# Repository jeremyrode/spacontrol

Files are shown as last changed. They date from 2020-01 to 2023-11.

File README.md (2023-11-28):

# spacontrol
IoT Work for my Caldera Vacanza Hot Tub

## General Info
I have a Caldera Vacanza Hot Tub in my house and I love it, with one exception: it heats on demand.  With electric time of use (TOU) rates, I can save money if the hot tub would heat during off-peak rates.  Goal is to reverse engineer the protocol used to signal button presses.  Phase 1 is to have a cron script adjust the setpoints so that the heating occurs during off-peak hours.  Phase 2 (current) is to use Google Calendar to schedule the virtual button presses to follow the complex TOU schedule.  Phase 3 (In progress) is to reverse engineer the status screen protocol, and forward the status to a website.  This has been stymied by the complex bit banging that is going on between these systems.  The patterns seem to change, see Keypad Commands section.

## Status

Phase 2 is working well for a year now, it pulls the desired temprature from a [Google Calendar via the API](/googlecalendardaemon), then schedules them.  I thought this was clever, so [I broke out this code as an example](https://github.com/jeremyrode/CalendarScraper) and it made [HACAKADAY!](https://hackaday.com/2022/10/25/using-google-calendar-for-machines-to-keep-track-of-human-days/)

## Quickstart

Easiest way is to have a cron job running tools/temp_up.js and tools/temp_down.js at the appropriate times for cheap TOU power.

Add the following to the crontab:
```
08 0 * * * /home/pi/spacontrol/tools/temp_down.js
10 0 * * * /home/pi/spacontrol/tools/temp_up.js
50 5 * * * /home/pi/spacontrol/tools/temp_down.js
```
Here at 12:08 AM the temp is turned down to ensure a start from 80 deg, as this code is "open-loop".  At 12:10 AM the temp is turned up to 103, then at 5:50AM the temp is turned back down to 80 deg.  Ideally the spa will be at ~100 deg in the evening when I'm ready to go in.

## Detailed Status
I have successfully reverse engineered the button press protocol.  Playing the protocol back proved to be tricky, as the keypad seems to be polled, so even when no buttons are pressed, the keypad reports status every ~40ms.  Injecting commands on top of the polled screen traffic does not result in the controller registering a button press. I suspect there is a switch "debouncing" algorithm that only registers a press if button polls several times in a row.  This necessitated a more complicated hardware design, where a GPIO on the raspberry pi is used to switch a mux, muting the traffic from the screen while virtual button presses are generated.

## Screen status 
77 degrees
Mostly
4a962bf252fefefa6600
I saw one:
4a962be452fefefa6600
80 degrees
4a962bf252fefefa6600

## Keypad Commands

The keypad seems to report status every ~40ms back to the controller.  I believe it is polled based off of commands sent to the pad, as the traffic seems to halt if the controller->keypad serial line is disconnected.  Baud rate is 115200, with 2-stop bits, but this doesn't seem to matter.

| Button  | Code (Hex) |
| :---: |:----:|
| Idle | 584D5300036b00000166 |
| Unknown / Idle  | 584D5300014b0144 |
| Jets | 584D5300036b00100176 |
| Temp Down | 584D5300036b0008016e |
| Temp Up | 584D5300036b00020168 |
| Lights | 584D5300036b00200186 |

Some how this has changed???

Now I'm seeing at idle (captured with serial_test.py):

58534d00010000f958534d00031a00830198

58534d00031a00830198

58534d00031a00830198

58534d00031a00830198

58534d00010000f958534d00031a00830198

58534d00031a00830198

No idea!, but the old commands seem to work on the sending side!

Seems to persist.  Is the the raspberryPi or the mainboard?

Putting this on hold, quite frankly it doesn't matter, the old commands above still work.

## Hardware details

This is the connector we would like to inject commands into:

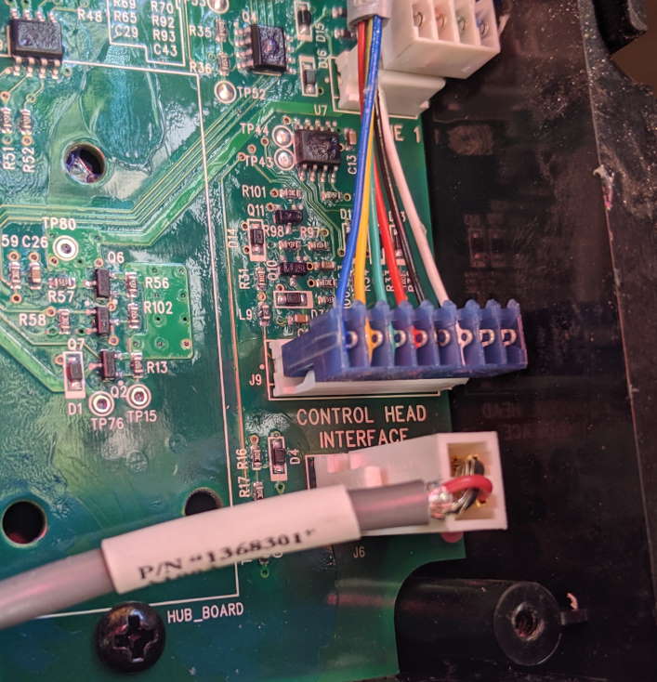
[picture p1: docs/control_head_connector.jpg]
Control Head Connector


Probing with an oscilloscope revealed the following pinout:

| Pin #  | Function |
| :---:|:----:|
| 1 | Screen->Controller (RS-422) |
| 2 | +12V |
| 3 | Controller->Screen (RS-422) |
| 4 | GND |
| 5 | Controller->Screen (RS-422) |
| 6 | Screen->Controller (RS-422) |

I have purposely not marked the RS-422 polarity, as I want to double check.  The PCB has jumpers that toggle the MAX3089's polarity inputs, so the PCB as designed will work with either polarity.

My first hand-built prototype.  

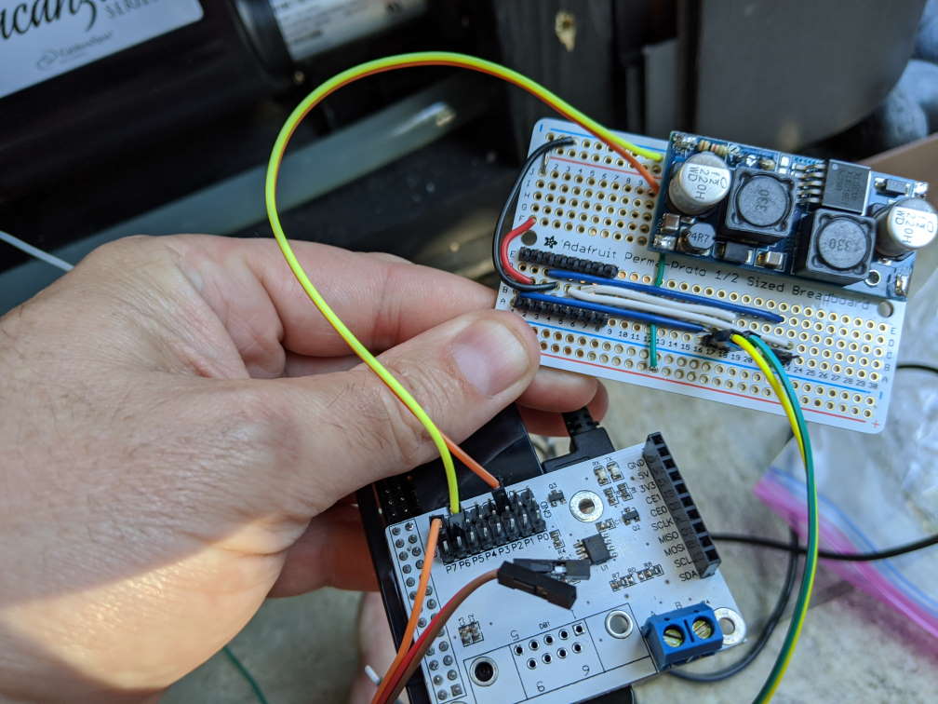
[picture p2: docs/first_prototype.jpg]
First Prototype


This is basically a break-out board, with a 12V to 5V converter for convenience so that I don't have to use an extension cord with a USB power supply to power the Pi Zero.  I used the [sparkfun RS485 shield](https://www.sparkfun.com/products/retired/13706) I had laying around from my [last reverse engineering project](https://github.com/jeremyrode/elancontrol).

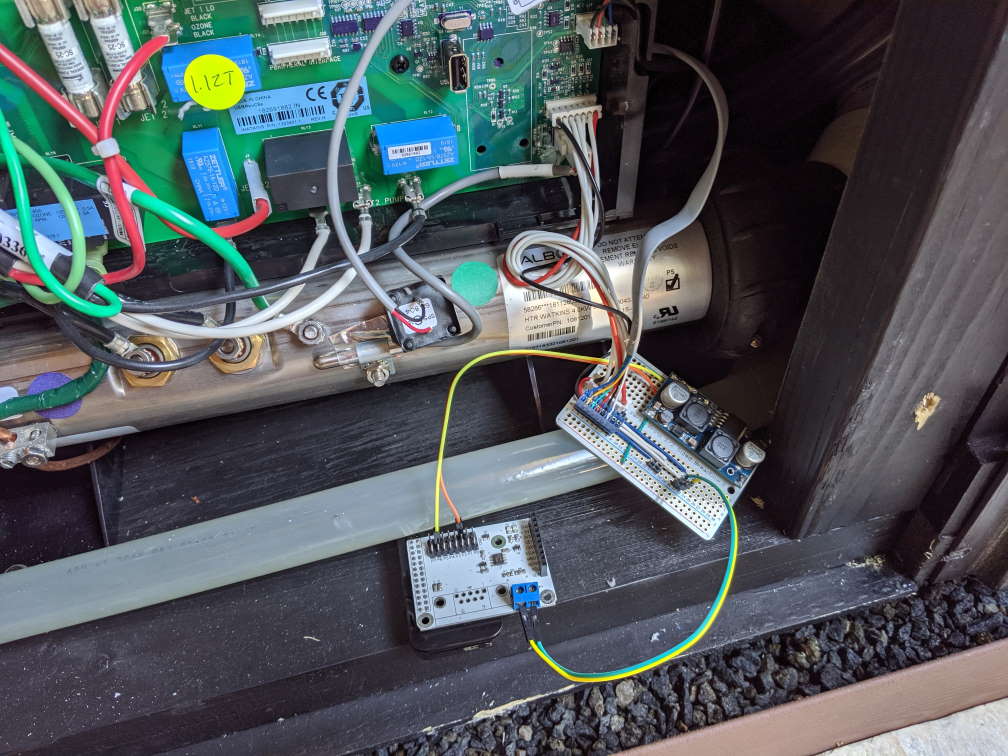
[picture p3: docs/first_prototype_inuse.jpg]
First Prototype In Use


This prototype successfully captured screen codes, and could play the codes back, but as its RS-422 transmitter is in parallel with the screens transmitter code playback never worked.  I suspect that because of the polled nature of the system transmitting status every 40ms, that when a button press code is injected some sort of button debouncing algorithm rejects the single button press code.  At this point I bit the bullet and I designed a raspberry Pi Zero "hat" PCB (see the PCB directory) that uses a MAX14778 MUX to inject commands (using a MAX3089 to translate the Pi's serial port to the spa's RS-422), defaulting to a passthrough mode where the normal screen traffic is unaffected, selected via GPIO5.  I also threw in a 12V to 5V regulator to power the raspberry Pi from the 12V screen supply.  Watch out the Vacanza controller will power cycle this 12V if valid commands are not returned for a couple of seconds or so!  That threw my debugging through a loop!

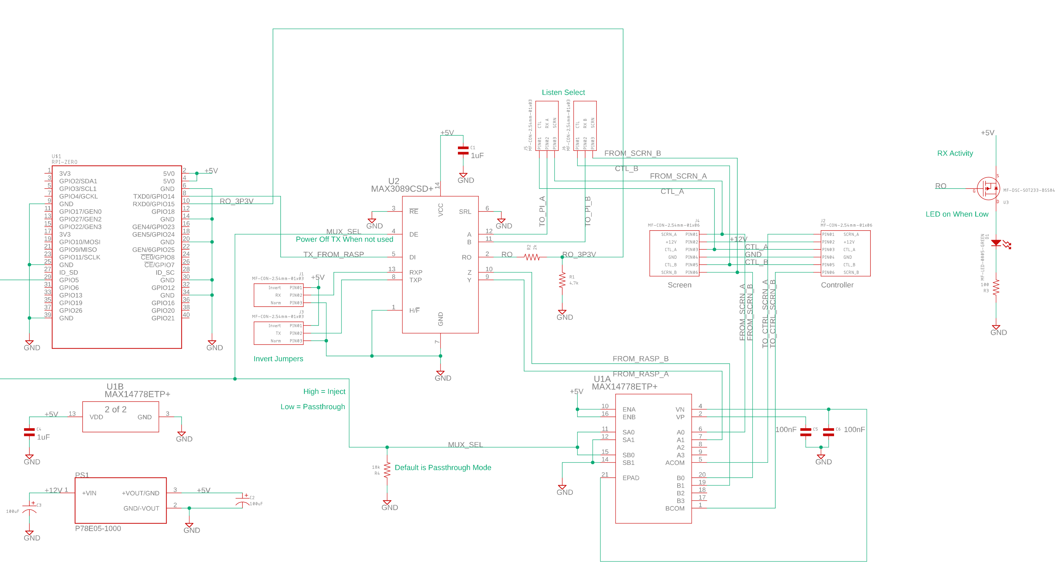
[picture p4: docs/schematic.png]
Interface PCB Schematic


Trusty Macrofab (I highly recommend!) fabricated it no problem:

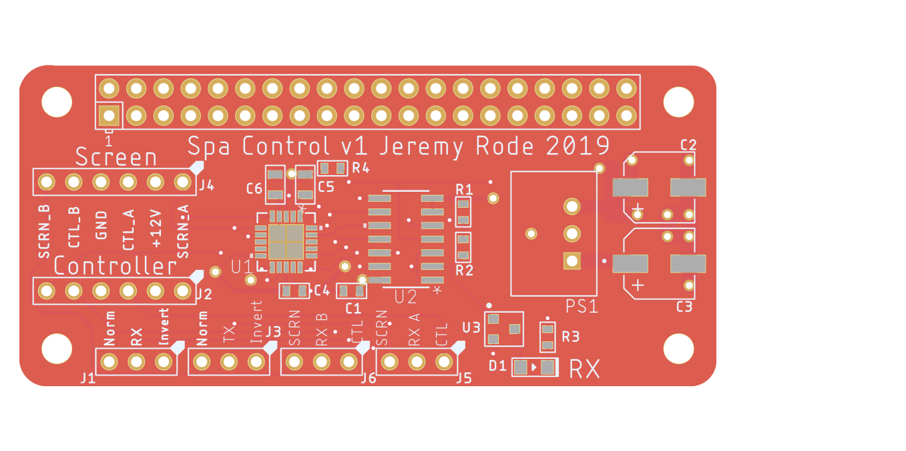
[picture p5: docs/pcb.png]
PCB


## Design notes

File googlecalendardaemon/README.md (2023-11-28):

# Spacontrol via Google calendar
## Status
Working for a year now!

## Details
Code polls a specified Google calendar, looks for events with 'Temp:'.  If these events are found, create the correct sequence of injected virtual button presses to achieve the desired temperature, no matter what the current setting is.

I plan to eventually incorporate circulation into the code, but first I need to get the current state from the screen.  Unlike the temperature where a known state can be achieved by hitting the limit, the jets button cycles through the states.  Without a method of determining the current state, there is no way to get the system reliably into a given state.

Default is 80 deg for all time except if there is no event.

## OAuth Drama

Google made getting a refresh token much harder (needing a publically avalible domain), so I switched this to a API key access method.  This is much easier, but has the side effect of only being able to access publically avalible calendars.  I see no need to keep my electric schedule private, so I make my spa control calendar public.

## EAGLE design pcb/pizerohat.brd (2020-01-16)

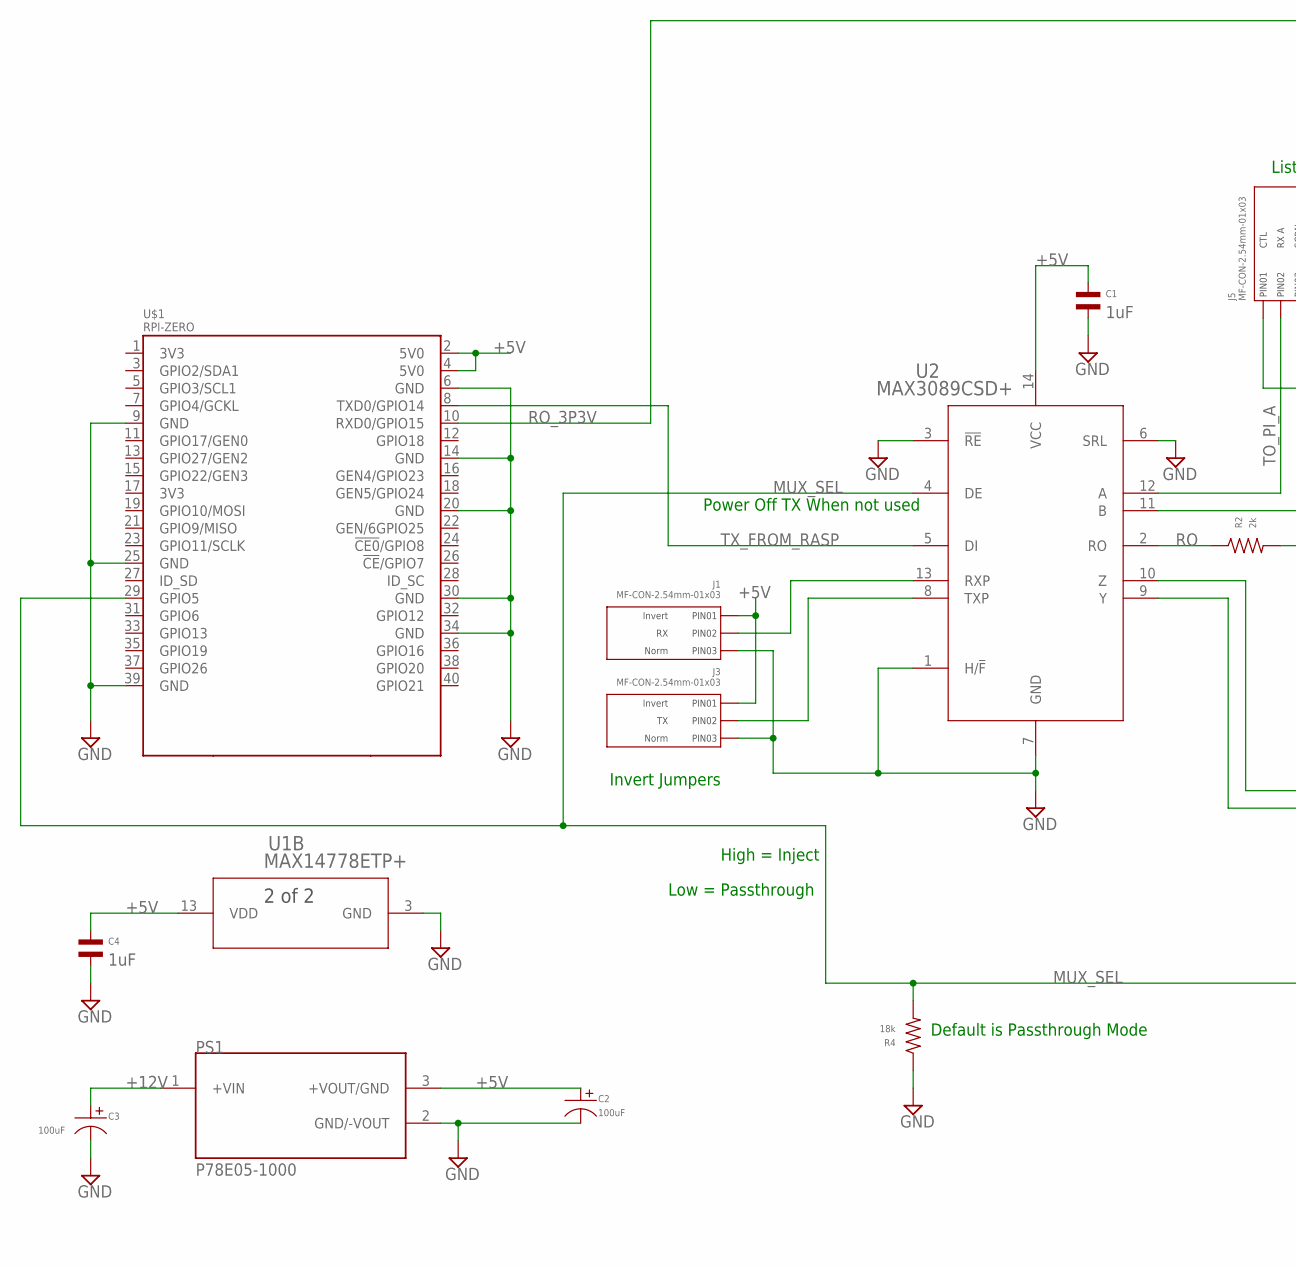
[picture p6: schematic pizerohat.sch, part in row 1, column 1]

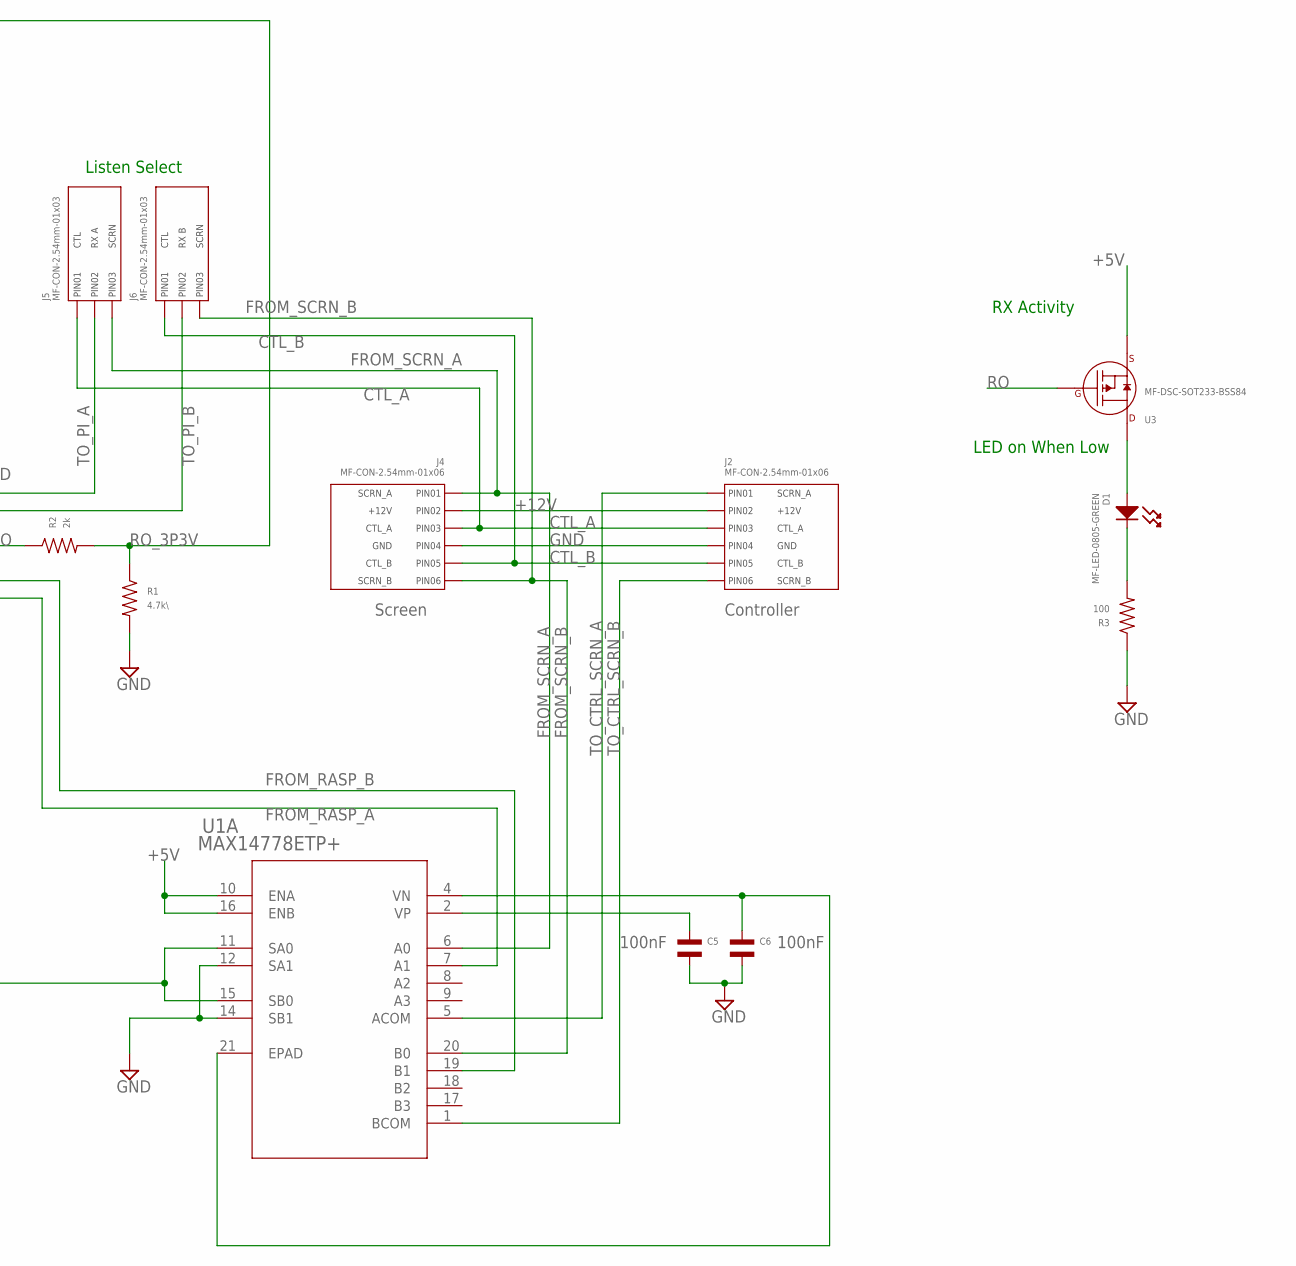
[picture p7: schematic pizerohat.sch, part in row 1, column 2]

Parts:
C1, C4: CAPACITOR_NP_0603; C0603; MPN MF-CAP-0603-1uF
C2, C3: 100uF; CP6.3MM; MPN MF-CAP-6.3MM-100uF
C5, C6: CAPACITOR_NP_0805; C0805; MPN MF-CAP-0805-0.1uF
D1: MF-LED-0805-GREEN; LED0805
J1, J3, J5, J6: MF-CON-2.54mm-01x03; PTH_2.54MM_01X03
J2, J4: MF-CON-2.54mm-01x06; PTH_2.54MM_01X06
PS1: P78E05-1000; CONV_P78E05-1000; MPN P78E05-1000
R1: 4.7k\; R0603; MPN MF-RES-0603-4.7K
R2: 2k; R0603; MPN MF-RES-0603-2K
R3: 100; R0603; MPN MF-RES-0603-100
R4: 18k; R0603; MPN MF-RES-0603-18K
U1: MAX14778ETP+; 21-0140L_T2055-4; MPN MAX14778ETP+
U2: MAX3089CSD+; 21-0041B_14; MPN MAX3089CSD+
U3: MF-DSC-SOT233-BSS84; SOT-23-3
U$1: RPI-ZERO; RASPBERRYPI_BASTELSTUBE_V13_RASPI_BOARD_B+_FULL

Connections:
+5V: C1.P$1, C2.P$1, C4.P$1, J1.P$1 (PIN1), J3.P$1 (PIN1), PS1.3 (+VOUT/GND), U1.10 (ENA), U1.13 (VDD), U1.16 (ENB), U2.14 (VCC), U3.P$2 (SOURCE), U$1.2 (5V0), U$1.4 (5V0)
+12V: C3.P$1, J2.P$2 (PIN2), J4.P$2 (PIN2), PS1.1 (+VIN)
CTL_A: J2.P$3 (PIN3), J4.P$3 (PIN3), J5.P$1 (PIN1)
CTL_B: J2.P$5 (PIN5), J4.P$5 (PIN5), J6.P$1 (PIN1)
FROM_RASP_A: U1.7 (A1), U2.9 (Y)
FROM_RASP_B: U1.19 (B1), U2.10 (Z)
FROM_SCRN_A: J4.P$1 (PIN1), J5.P$3 (PIN3), U1.6 (A0)
FROM_SCRN_B: J4.P$6 (PIN6), J6.P$3 (PIN3), U1.20 (B0)
GND: C1.P$2, C2.P$2, C3.P$2, C4.P$2, C5.P$2, C6.P$2, J1.P$3 (PIN3), J2.P$4 (PIN4), J3.P$3 (PIN3), J4.P$4 (PIN4), PS1.2 (GND/-VOUT), R1.P$2, R3.P$1, R4.P$1, U1.3 (GND), U1.12 (SA1), U1.14 (SB1), U2.1 (H/!F), U2.3 (!RE), U2.6 (SRL), U2.7 (GND), U$1.6 (GND), U$1.9 (GND), U$1.14 (GND), U$1.20 (GND), U$1.25 (GND), U$1.30 (GND), U$1.34 (GND), U$1.39 (GND)
MUX_SEL: R4.P$2, U1.11 (SA0), U1.15 (SB0), U2.4 (DE), U$1.29 (GPIO5)
unnamed: J1.P$2 (PIN2), U2.13 (RXP)
unnamed: J3.P$2 (PIN2), U2.8 (TXP)
unnamed: C6.P$1, U1.4 (VN), U1.21 (EPAD)
unnamed: D1.CATHODE, R3.P$2
unnamed: C5.P$1, U1.2 (VP)
unnamed: D1.ANODE, U3.P$3 (DRAIN)
RO: R2.P$1, U2.2 (RO), U3.P$1 (GATE)
RO_3P3V: R1.P$1, R2.P$2, U$1.10 (RXD0/GPIO15)
TO_CTRL_SCRN_A: J2.P$1 (PIN1), U1.5 (ACOM)
TO_CTRL_SCRN_B: J2.P$6 (PIN6), U1.1 (BCOM)
TO_PI_A: J5.P$2 (PIN2), U2.12 (A)
TO_PI_B: J6.P$2 (PIN2), U2.11 (B)
TX_FROM_RASP: U2.5 (DI), U$1.8 (TXD0/GPIO14)

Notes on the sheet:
Default is Passthrough Mode
RX Activity
LED on When Low
Invert Jumpers
Listen Select
High = Inject
Low = Passthrough
Power Off TX When not used

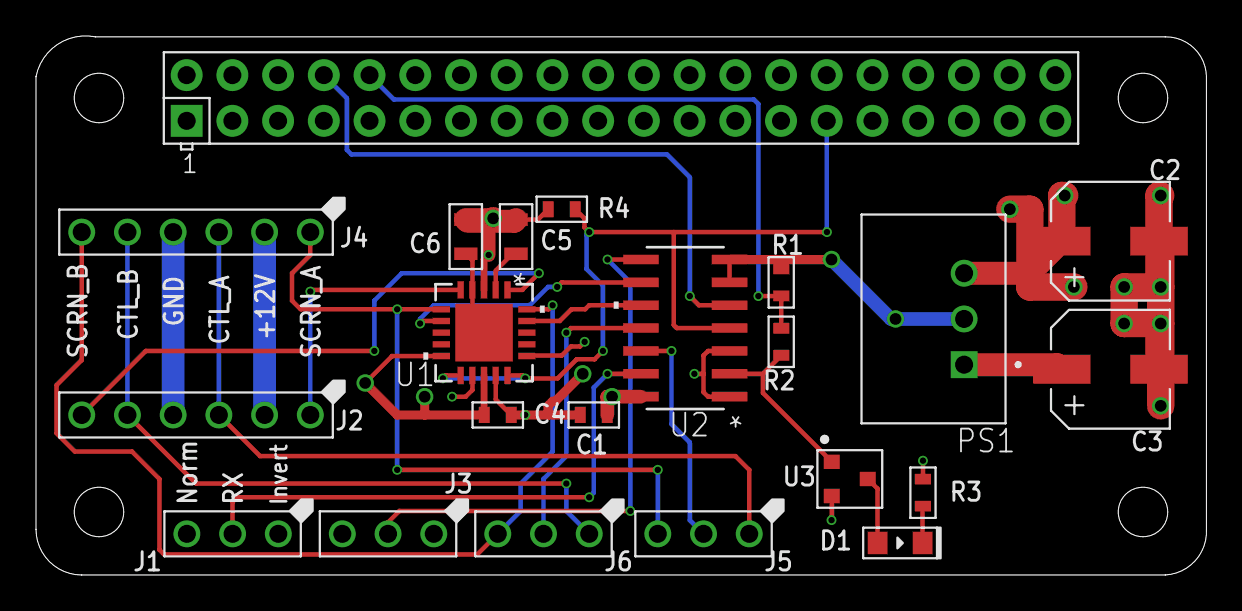
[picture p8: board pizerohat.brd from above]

Board: 4 copper layers, 65.0 x 29.9 mm, 22 parts (0 on the bottom side), 23 nets.

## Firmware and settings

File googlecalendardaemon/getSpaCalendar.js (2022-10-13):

#!/usr/bin/node
'use strict';
const fs = require('fs');
const {google} = require('googleapis');
const SerialPort = require('serialport');
const Delimiter = require('@serialport/parser-delimiter');
const Gpio = require('onoff').Gpio; //require onoff to control GPIO
const MUXPin = new Gpio(5, 'out'); //declare GPIO5, the muxpin as an output

process.title = 'GoogleCalendarDaemon';

// If modifying these scopes, delete token.json.
const SCOPES = ['https://www.googleapis.com/auth/calendar.events.public.readonly'];
const API_KEY_PATH = '/home/pi/google_api_key.json';
const LOG_FILE = '/home/pi/SpaCalendarLog.txt';
const UPDATE_INTERVAL = 30; //How often to poll Goolge canlendar In mins
const INTERVAL_OVERLAP = 1; //In mins to be sure we don't miss anything
const IDLE_TEMP = 80; //What temp when no event is scheduled
const LONG_PATTERN =  Buffer.alloc(10,'584D5300036b00000166','hex'); //No button pressed pattern
const TEMP_UP =       Buffer.alloc(10,'584D5300036b00020168', 'hex'); //Temp up presses pattern
const TEMP_DOWN =     Buffer.alloc(10,'584D5300036b0008016e', 'hex'); //Temp down presssed pattern
const VIRTUAL_PRESS_DELAY = 40; //delay in ms between vitual button presses
const VIR_PRESS_PAT_REPEAT = 5; //How many pattern repeats for each virtual press 10 is too many, registers mutiple sometimes
const NUM_VIRT_PRESS_TO_LIMIT = 26; //How many virtual presses to hit a limit
const DELAY_DOWN_TO_UP = 60000; //How long to wait between the two temp changes
//Globals
let pendingCommands = null; //Mutex for pending unexecuted commands
let errorsInAPI = 0; //Counter to limit requests to Google

// Log file for testing purposes
const logfile = fs.createWriteStream(LOG_FILE, {flags:'a'});
// Serial Port to send commands
const port = new SerialPort('/dev/serial0', {  baudRate: 115200 });

//Make sure at startup we don't control the serial bus
mux_off();
//If interrupted, turn mux off
process.on('SIGINT', _ => {
  MUXPin.writeSync(0);
  process.exit();
});

// logging function
function combinedLog(message) {
  let curDate = new Date();
  let dateStr = curDate.toString();
  message = dateStr.slice(0,dateStr.length-33) + ':' + curDate.getMilliseconds() + ': ' + message; //Prepend Time to message
  console.log(message);
  logfile.write(message + '\n')
}

// Load API Key from a local file.
fs.readFile(API_KEY_PATH, (err, content) => {
  if (err) return combinedLog('Error loading API key file:', err);
  // Authorize a client with credentials, then call the Google Calendar API.
  const obj = JSON.parse(content);
  planEvents(obj.api_key, obj.google_cal_id); //Do a plan now
  setInterval(planEvents, UPDATE_INTERVAL*60000, obj.api_key,obj.google_cal_id); //Replan
  combinedLog('New Session');
});


function planEvents(api_key, google_cal_id) { //Plan out the current interval
  const calendar = google.calendar({version: 'v3', auth: api_key});
  const planStartDate = new Date;
  planStartDate.setSeconds(planStartDate.getSeconds() + 10); //Give us a ten sec delay for causality
  const planEndDate = new Date(planStartDate.getTime()); //Clone current time
  planEndDate.setMinutes(planStartDate.getMinutes() + UPDATE_INTERVAL + INTERVAL_OVERLAP); // Next interval
  if (pendingCommands) { //We have unexed commands, this happens
    combinedLog('We had pending events at: ' + pendingCommands.toString());
    let delay = Math.abs(pendingCommands - Date.now())+10;
    if (delay < UPDATE_INTERVAL * 60000 ) { //if the normal update wont get it
      setTimeout(planEvents,delay, api_key, google_cal_id); //Call ourself in the future
      combinedLog('Recall planEvents() in ' + delay + ' ms');
    }
    return; // don't plan
  }
  calendar.events.list({
    calendarId: google_cal_id,
    timeMin: planStartDate.toISOString(),
    timeMax: planEndDate.toISOString(),
    maxResults: 10,
    singleEvents: true,
    orderBy: 'startTime',
  }, (err, res) => {
    if (err) {
      combinedLog('The Google API request returned an error: ' + err);
      errorsInAPI += 1;
      combinedLog('We have ' + errorsInAPI + ' running errors');
      if (errorsInAPI < 10) { //For now limit us to 10 extra requests
        setTimeout(planEvents,60000,api_key,google_cal_id); //Call ourself one min in the future
        combinedLog('Recall planEvents() in one min');
      }
      return; //don't plan
    }
    errorsInAPI = 0; //Reset error counter
    const events = res.data.items;
    //combinedLog('Got ' + events.length + ' events!' );
    for (let event of events) {
      const eventStart = new Date(event.start.dateTime);
      const eventEnd = new Date(event.end.dateTime);
      let summary = event.summary.split(":"); //Look for desired temp
      let desired_temp = parseInt(summary[1],10);
      if (summary.length == 2 && summary[0].trim() == 'Temp' &&
      Number.isInteger(desired_temp) && desired_temp > 79 && desired_temp < 105) { //Validate Summary
         //combinedLog('Got Valid Temp of: ' + desired_temp);
         if ( eventStart >= planStartDate ) { //If the event starts after interval start, need a temp up event
           //combinedLog('Temp Up to ' + desired_temp + ' Event Found at start: ' + eventStart.toString());
           scheduleTemp(desired_temp, eventStart); //Schedule the temp change
         }
         if ( eventEnd <= planEndDate ) { //If the event ends before the interval end, need a temp down event
           //combinedLog('Temp Down Event Found at end: ' + eventEnd.toString());
           scheduleTemp(IDLE_TEMP, eventEnd); //Schedule the temp change
         }
      }
      else { //If not valid, do nothing
        combinedLog('Malformed Event Summary: ' + event.summary)
      }
    }
  });
}

function scheduleTemp (temp,atTime) { //Set Temp from a limit, so we don't need to know what current temp setting is
  let msecsInFuture  = Math.abs(atTime - Date.now());
  if (temp >= 104) { //This is the limit, so just go there with extra presse
    tempCommand(NUM_VIRT_PRESS_TO_LIMIT,true,msecsInFuture,false); //Ensure we are at 104 by going up a bunch
    tempCommand(NUM_VIRT_PRESS_TO_LIMIT,true,msecsInFuture + DELAY_DOWN_TO_UP,true); //Double ensure
  }
  else {
    if (temp > 80) { //If above 80, go there after a delay
      tempCommand(NUM_VIRT_PRESS_TO_LIMIT,false,msecsInFuture,false); //Ensure we are at 80 by going down a bunch
      tempCommand(temp-79,true,msecsInFuture + DELAY_DOWN_TO_UP,true); //Go up from 80 after delay, first press is lost
    }
    else {
      tempCommand(NUM_VIRT_PRESS_TO_LIMIT,false,msecsInFuture,false); //Ensure we are at 80 by going down a bunch
      tempCommand(NUM_VIRT_PRESS_TO_LIMIT,false,msecsInFuture + DELAY_DOWN_TO_UP,true); //Double Ensure
    }
  }
}
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

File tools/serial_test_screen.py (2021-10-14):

#!/usr/bin/env python3
import datetime
import serial

ser = serial.Serial(
    port='/dev/serial0',
    baudrate = 115200,
#    parity=serial.PARITY_NONE,
#    stopbits=serial.STOPBITS_ONE,#35B (minus 6 bits) with two stop bits
#    bytesize=serial.EIGHTBITS,  # 38 bytes with one stop bit
    #timeout=0.05,
    )
old=ser.read(10)
#old_bin_string = bin(int(old.hex(),16))
print(old.hex())
while True:
    data=ser.read(10)
    if (data != old):
        #bin_string = bin(int(data.hex(),16))
        print(data.hex())
        old = data

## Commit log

2019-11-26 pcb inital checkin
2019-11-30 PCB Update
    [pizerohat.brd, pizerohat.sch]
2019-11-30 Rordered mux pins, added pulldown for default muxsel
    [pizerohat.brd, pizerohat.sch]
2019-12-01 Power TX down when not in use
    [pizerohat.brd, pizerohat.sch]
2020-01-16 Working with new PCBgit status
2021-09-24 Spa command sending integrated, short term tested
    [getSpaCalendar.js]
2021-09-30 Cleaned up Auth, had errors afeter 5 days
    [getSpaCalendar.js]
2021-11-18 about to add reliability for overnight heats
2021-11-18 add reliability for overnight heats
